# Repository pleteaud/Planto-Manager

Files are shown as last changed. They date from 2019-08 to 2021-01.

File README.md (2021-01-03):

# Planto-Manager

## Description: 
This is an embedded project aimed at monitoring and caring for a potted plant. Device is able to monitor room temperature and humidity using the [DHT11](https://www.adafruit.com/product/386). It can also measure the soil moisture by utilizing a personally designed soil moisture sensor, influenced by [Grove's Capacitor Soil Moisture Sensor](https://wiki.seeedstudio.com/Grove-Capacitive_Moisture_Sensor-Corrosion-Resistant/). Additionally, the device is able to track time and set alarms using the [DS3231](https://components101.com/modules/ds3231-rtc-module-pinout-circuit-datasheet) RTC module. A [16x2 Character LCD](https://www.sparkfun.com/products/709)  was used to display relevant information. Lastly, given the simplicity of the tasks and the low cost, the firmware was developed on an Atmega328P.

## Libraries:
  [Atmel Start Configuration Files](https://start.atmel.com/#dashboard)

## Images:

### Planto Manager System 
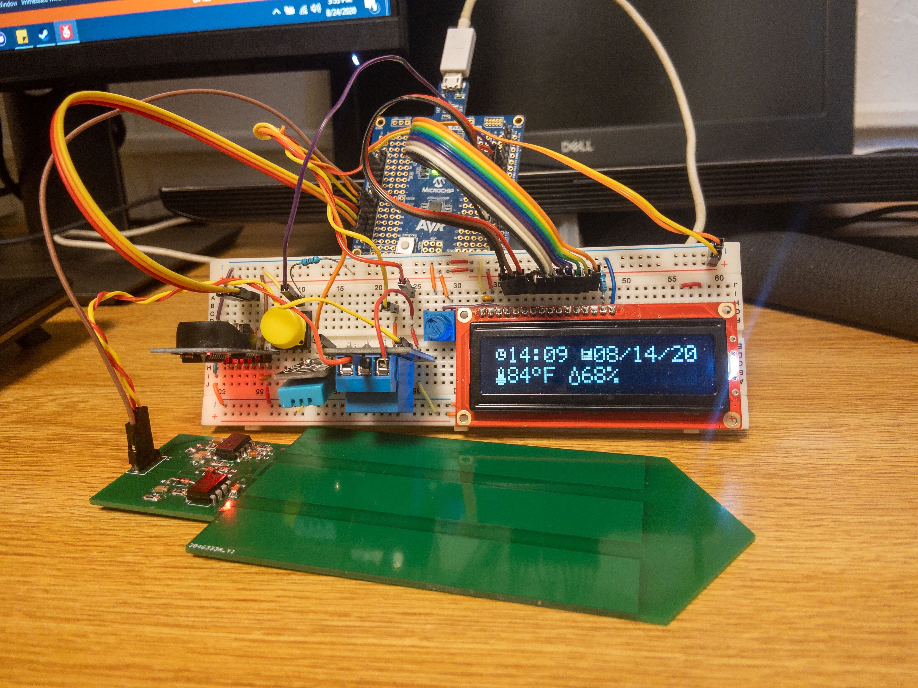
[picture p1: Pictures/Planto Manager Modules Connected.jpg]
Planto Manager System


### Planto Manager System Wiring
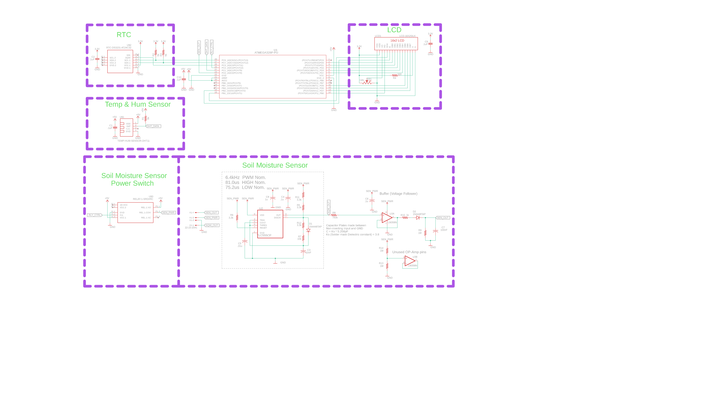
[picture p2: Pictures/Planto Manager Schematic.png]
Planto Manager System Wiring


### Soil Moisture Sensor PCB Layout
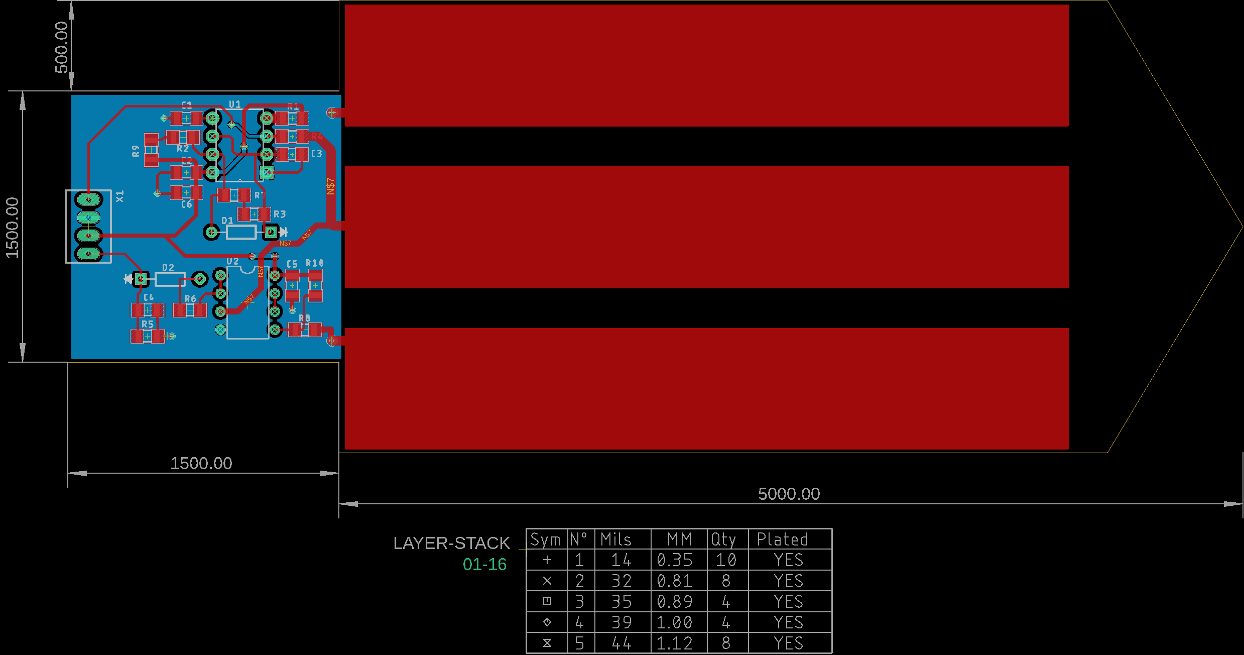
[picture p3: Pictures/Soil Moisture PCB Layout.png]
Soil Moisture Sensor PCB Layout


### Soil Moisture Sensor Reading (Dry Case)
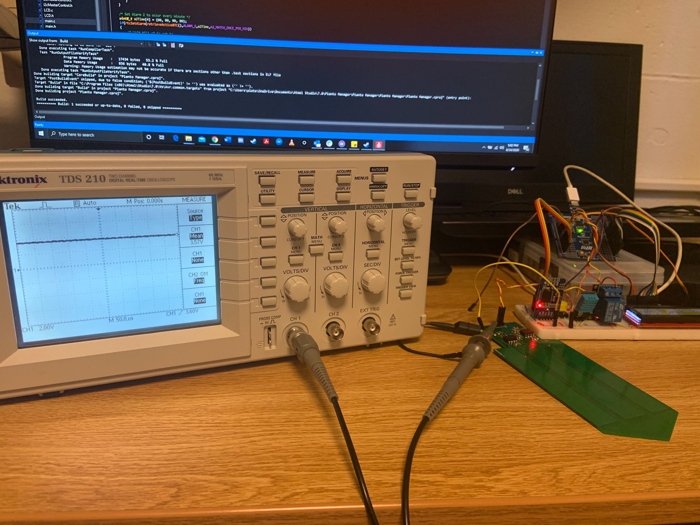
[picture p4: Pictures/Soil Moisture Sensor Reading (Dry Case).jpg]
Soil Moisture Sensor Reading (Dry Case)


### Soil Moisture Sensor Reading (Moist Case)
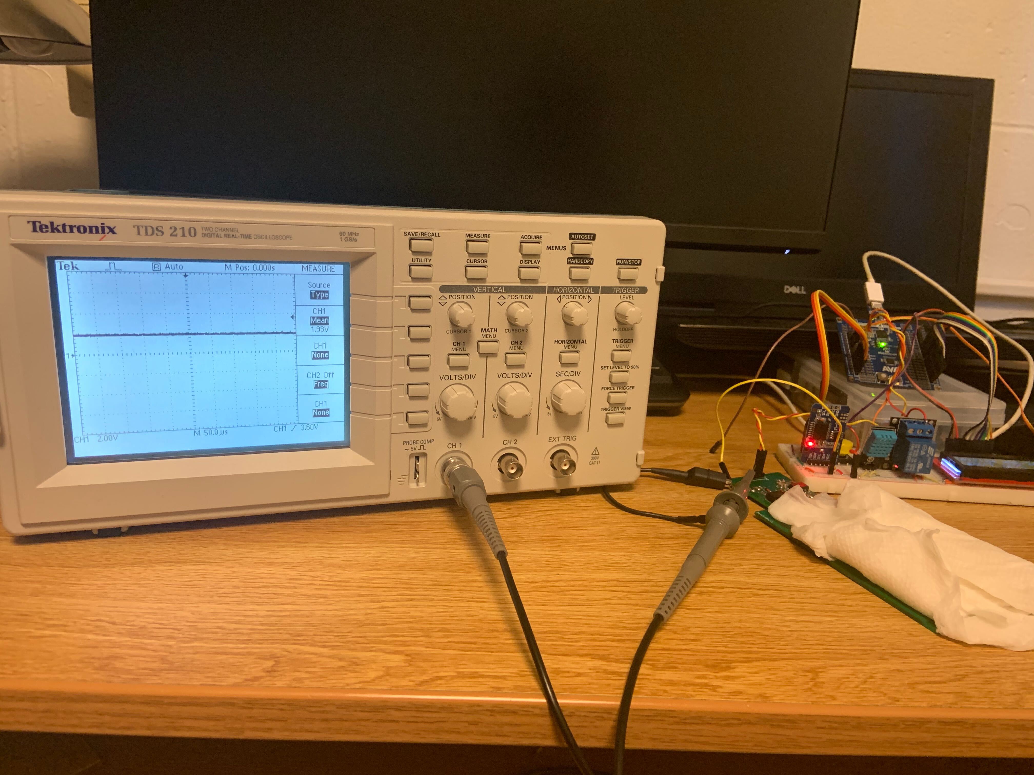
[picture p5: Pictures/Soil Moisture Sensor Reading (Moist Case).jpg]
Soil Moisture Sensor Reading (Moist Case)


## Future Plan
- [ ] Switch to Adafruit BME280 sensor since it supports I2C. This will free up pins and reduce the timing issues faced with the DHT11
- [ ] Implement a Keypad module to allow user to inter inferace with device out of debug mode.
- [ ] Fix Soil moisture sensor code bugs.
- [ ] Implement I2C I/O Expander (MCP23017-E/SP-ND) to reduce number of pins used by the LCD and Keypad
- [ ] Implement reworks and design upgrades to Soil Moisture Sensor
- [ ] Design and build container for device

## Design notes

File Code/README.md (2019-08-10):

# Plant-Manager
Embedded project to manage and track a garden's progress

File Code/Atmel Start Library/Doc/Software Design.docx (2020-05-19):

Software Design:

- What should our microcontroller be able to do
  - Turn on the water pump to water the plants
    - Is it possible to vary how much water is being pumped by varying how fast the pump is moving?
    - Use a Normally-Open Single Pole Single Throw relay to turn on and off the water pump.
  - Calculate how moist or dy the soil is
    - Maybe calculate how long it takes for the soil to typically dry up within a week?
    - Use two probs to measure the resistance between the soil.
  - Gather data about temperature, humidity
    - If temperature is super-hot it could be worth implementing a failsafe to turn on the water to water them. But maybe we should check the moisture first.
    - Connect temp/humidity sensor to adc channels of microcontroller
  - Notify user if there’s no water
    - Send user an email/text/ some for of notification when water reservoir is empty
  - Plant Stats
    - Keep track of height of plants
    - Determine if plant has produced veggies
    - Determine if those veggies are good /have fallen?
    - Store these data somewhere

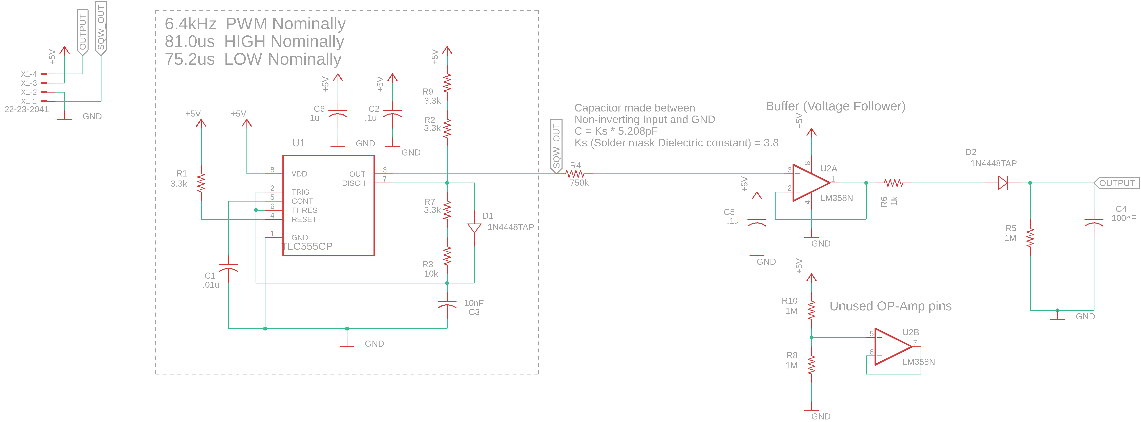
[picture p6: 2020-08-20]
Pictures/Soil Moisture Schematic.png

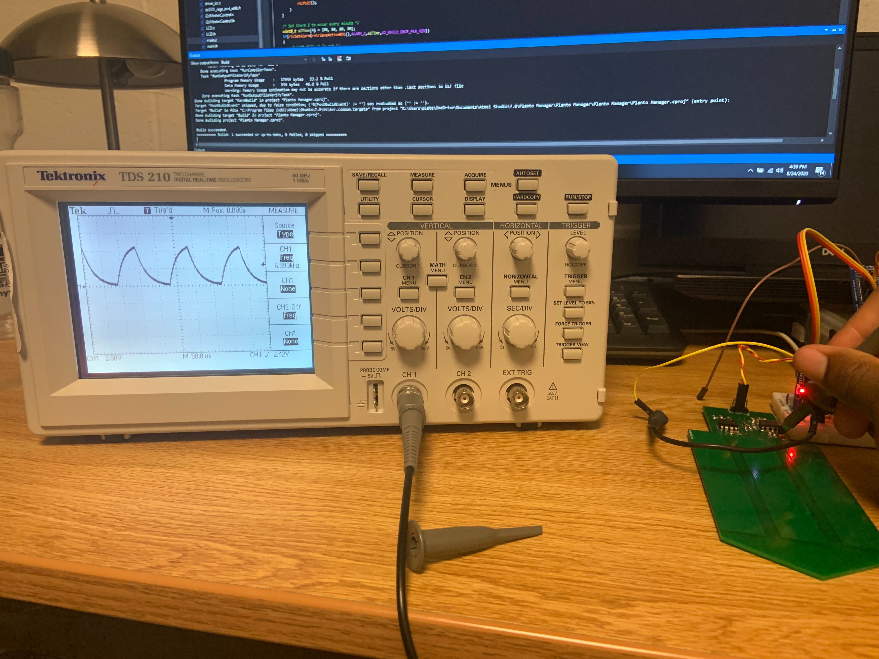
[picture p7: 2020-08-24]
Pictures/Passive Intergrator Signal.jpg

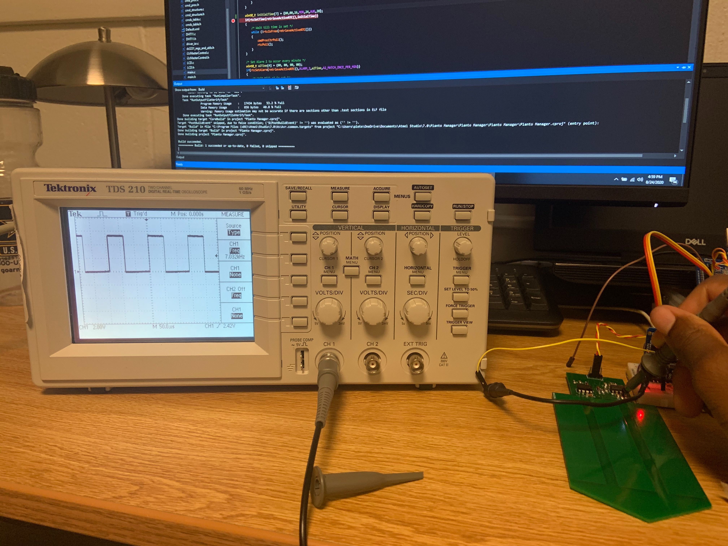
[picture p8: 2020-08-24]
Pictures/Output of Timer 555.jpg

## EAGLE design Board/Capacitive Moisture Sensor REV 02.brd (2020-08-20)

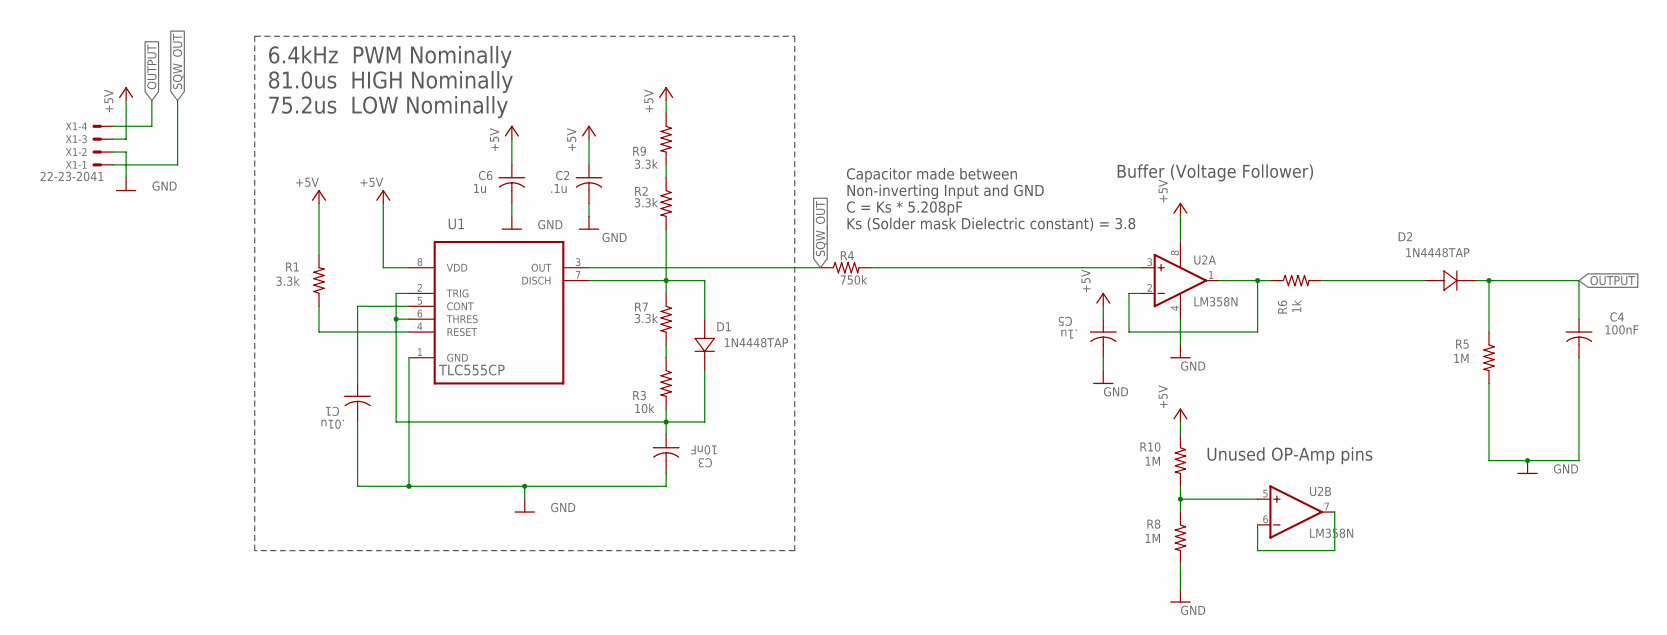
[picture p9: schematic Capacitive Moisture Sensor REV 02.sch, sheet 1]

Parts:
C1: .01u; C1206
C2, C5: .1u; C1206
C3: 10nF; C1206
C4: 100nF; C1206
C6: 1u; C1206
D1, D2: 1N4448TAP; DO-35
R1, R2, R7, R9: 3.3k; R1206
R3: 10k; R1206
R4: 750k; R1206
R5, R8, R10: 1M; R1206
R6: 1k; R1206
U1: TLC555CP; DIP254P762X508-8
U2: LM358N; DIL08
X1: 22-23-2041

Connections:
+5V: C2.1, C5.1, C6.1, R1.2, R9.1, R10.1, U1.8 (VDD), U2.8 (V+), X1.3
GND: C1.2, C2.2, C3.2, C4.2, C5.2, C6.2, R5.2, R8.2, U1.1 (GND), U2.4 (V-), X1.2
unnamed: U2.6 (-IN), U2.7 (OUT)
unnamed: C3.1, D1.1, R3.2, U1.2 (TRIG), U1.6 (THRES)
unnamed: R1.1, U1.4 (RESET)
unnamed: C1.1, U1.5 (CONT)
unnamed: D2.2, R6.2
unnamed: R3.1, R7.2
unnamed: R4.2, U2.3 (+IN)
unnamed: R2.1, R9.2
unnamed: R6.1, U2.1 (OUT), U2.2 (-IN)
unnamed: D1.2, R2.2, R7.1, U1.7 (DISCH)
unnamed: R8.1, R10.2, U2.5 (+IN)
OUTPUT: C4.1, D2.1, R5.1, X1.4
SQW_OUT: R4.1, U1.3 (OUT), X1.1

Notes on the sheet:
Buffer (Voltage Follower)
6.4kHz PWM Nominally 81.0us HIGH Nominally 75.2us LOW Nominally
Capacitor made between Non-inverting Input and GND C = Ks * 5.208pF Ks (Solder mask Dielectric constant) = 3.8
Unused OP-Amp pins

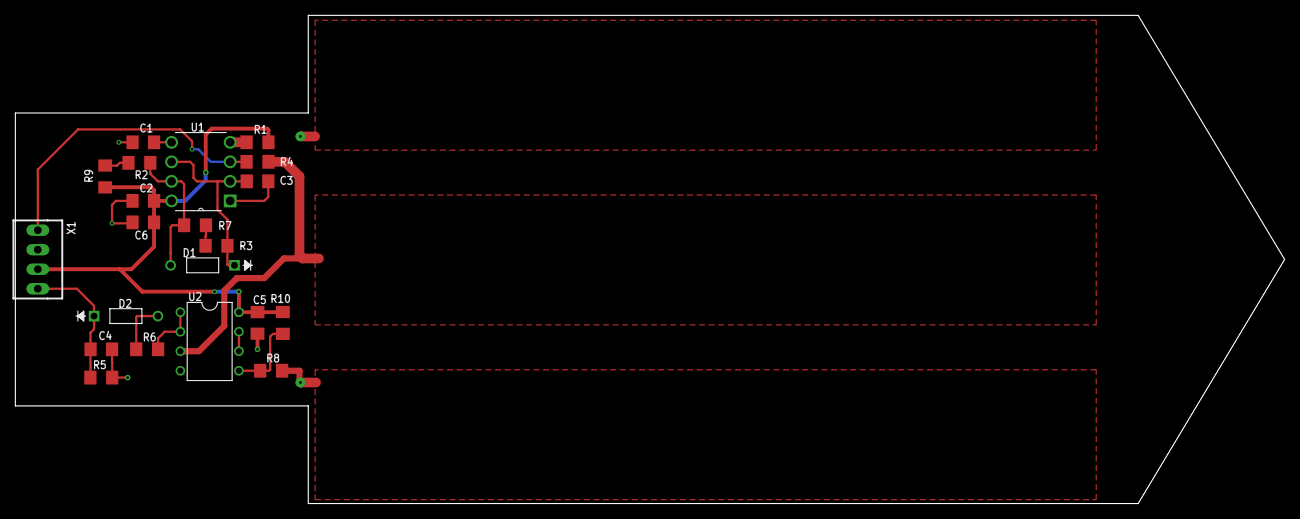
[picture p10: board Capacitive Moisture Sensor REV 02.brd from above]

Board: 2 copper layers, 165.1 x 63.5 mm, 22 parts (0 on the bottom side), 15 nets.

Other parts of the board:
DRILEGEND: DRILEGEND

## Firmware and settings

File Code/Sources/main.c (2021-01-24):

#include "main.h"

/* Instantiate LCD, RTC, and BME sensor */
lcd_t lcd;
ds3231_t ds3231;
struct bme280_dev dev;
mcp23017_t ioExpander;
keypad_t keypad;

/* Custom Pattern byte for clock */
unsigned char clockSymbol[] = {0x0,0xe,0x15,0x17,0x11,0xe,0x0,0x00};
uint8_t clkSymLoc = 0;
unsigned char calendarSymbol[] = {0x00,0x11,0x1F,0x13,0x1F,0x1F,0x00,0x00};
uint8_t calSymLoc = 1;

/* Custom pattern bytes for BME sensor */
unsigned char thermoSym[] = {0x04,0x0A,0x0A,0x0E,0x0E,0x1F,0x1F,0x0E};
uint8_t thermSymLoc = 2;
unsigned char degreeSym[] = {0x0C,0x12,0x12,0x0C,0x00,0x00,0x00,0x00};
uint8_t degreeSymLoc = 3;
unsigned char humiditySym[] = {0x04,0x04,0x0A,0x0A,0x11,0x11,0x11,0x0E};
uint8_t humiditySymLoc = 4;

void setTime(ds3231_t *ds3231P, lcd_t *lcdP, keypad_t *keypad);
static uint32_t readDigit(keypad_t *keypadP, char *str);
static void printErrorMessage(lcd_t *lcdP, char *msg);

static bool updateFlag = false;
int main(void)
{
 	/* Initializes MCU, drivers and middleware */
 	atmel_start_init();
	 
 	// Start free running timer 
 	startMillisTimer();
 	/* Initialize keypad */
 	keypadInit(&keypad);

 	/* Initialize I2C */
  	i2cMasterInit(0);

  	/* Initialize mcp23017 */
  	mcp23017Init(&ioExpander, 0, &DDRB, &PORTB, PINB3); // Pin B 3 is reset pin

 	
 	/* Initialize LCD */
 	lcdInit(&lcd, &ioExpander, &DDRB, &PORTB, PINB0, PINB1, PINB2, true, false);

// 	/* Initialize bme sensor */
// 	uint8_t devAddr = BME280_I2C_ADDR_PRIM;
// 	initBME(&dev, userI2cRead, userI2cWrite, userDelayUs, &devAddr);
// 	
 	/* Initialize and Configure RTC */
 	ds3231Init(&ds3231);
	 
 	// Set Alarm 2 to occur every minute
 	uint8_t a2Time[4] = {00, 00, 00, 00};	 
	ds3231SetAlarm2(&ds3231, a2Time, A2_MATCH_ONCE_PER_MIN, setUpdateFlag, NULL);
 	
	// Set time 
 	printTime(&lcd, &ds3231);
 	printSymbols(&lcd);
 	setTime(&ds3231, &lcd, &keypad);

	/* Build and print special symbols */

 	char s;
 	while(1)
 	{
 		s = getKeyPress(&keypad);
 		ds3231Poll(&ds3231);
 		if(updateFlag)
 		{
 			printTime(&lcd, &ds3231);
 			//if(!getSensorDataForcedMode(&lcd, &dev))
//
 			//{
//
 				////print error
//
 			//}

 			updateFlag = false;

 		}
 	}
	
}

/* Alarm 2 callback function to indicate ds3231 has been updated */
void setUpdateFlag()
{
	updateFlag = true;
}

/* Print time on LCD */
void printTime(lcd_t *lcdP, ds3231_t *ds3231P)
{
	// Set cursor to (0,1) to print Hour:Min in LCD
	lcdSetCursor(lcdP, 0, 1);
	char lcdBuff[20] = {0};
	
	// Print Hour and Minute
	snprintf(lcdBuff, 20, "%02x:%02x", ds3231.time[TIME_UNITS_HR], ds3231.time[TIME_UNITS_MIN]);
	lcdPrint(lcdP, lcdBuff);
	
	// Set cursor to (0,7) to print Date/month/year on LCD 
	lcdSetCursor(lcdP, 0, 8);
	
	// Print date
	snprintf(lcdBuff, 20,"%02x/%02x/%02x", ds3231.time[TIME_UNITS_MO_CEN] & 0x1F, ds3231.time[TIME_UNITS_DT],
										ds3231.time[TIME_UNITS_YR]);
	lcdPrint(lcdP, lcdBuff);
	lcdHome(lcdP);
}

/* Print and Build symbols. Will only be called once */
void printSymbols(lcd_t *lcdP)
{
	/* Build and print themometer and degree symbol */
	lcdBuildSym(lcdP, thermSymLoc,thermoSym);
	lcdBuildSym(lcdP, degreeSymLoc,degreeSym);
	lcdSetCursor(lcdP, 1,0);
	lcdPrintSymbol(lcdP, thermSymLoc);
	lcdSetCursor(lcdP, 1,6);
	lcdPrintSymbol(lcdP, degreeSymLoc);
	lcdPrint(lcdP, "F");
	
	/* Build and print humidity symbol*/
	lcdBuildSym(lcdP, humiditySymLoc,humiditySym);
	lcdSetCursor(lcdP, 1,9);
	lcdPrintSymbol(lcdP, humiditySymLoc);
	lcdSetCursor(lcdP, 1,15);
	lcdPrint(lcdP, "%");
	
	/* Build and Print clock symbol */
	lcdBuildSym(lcdP, clkSymLoc, clockSymbol); 
	lcdSetCursor(lcdP, 0,0);
	lcdPrintSymbol(lcdP, clkSymLoc);
	
	/* Build and print calendar symbol */
	lcdBuildSym(lcdP, calSymLoc,calendarSymbol);
	lcdSetCursor(lcdP, 0,7);
	lcdPrintSymbol(lcdP, calSymLoc);
	
	/* Print moisture Symbol */	
	
	lcdHome(lcdP);
}

/* Print BME280 temperature, humidity, and pressure */
void printBMEdata(lcd_t *lcdP, struct bme280_data *comp_data)
{
	
	float temp, press, hum;
		temp = 0.01f * comp_data->temperature;
		press = 0.0001f * comp_data->pressure;
		hum = 1.0f / 1024.0f * comp_data->humidity;
	
	#ifdef BME280_FLOAT_ENABLE
		temp = comp_data->temperature;
		press = 0.01 * comp_data->pressure;
		hum= comp_data->humidity;
	#else
	#ifdef BME280_64BIT_ENABLE
		temp = 0.01f * comp_data->temperature;
		press = 0.0001f * comp_data->pressure;
		hum = 1.0f / 1024.0f * comp_data->humidity;
	#else
		temp = 0.01f * comp_data->temperature;
		press = 0.01f * comp_data->pressure;
		hum = 1.0f / 1024.0f * comp_data->humidity;
	#endif
	#endif
	
	/* Print temperature */
	char lcdBuff[20] = {0}; // lcd buffer
	
	temp = (temp * 1.8) + 32; //convert to F
	
	/* Get interger and fractional value to print on lcd (floats don't work)*/
	unsigned int intergralVal = temp; 
	unsigned int fractionalVal = (temp - (uint32_t)temp) * 100;
	
	snprintf(lcdBuff, 20, "%u.%02u", intergralVal, fractionalVal);
	lcdSetCursor(lcdP, 1, 1);
	lcdPrint(lcdP, lcdBuff); // print
	
	/* Print humidity */
	intergralVal = hum;
	fractionalVal = (hum - (uint32_t)hum) * 100;
	
	snprintf(lcdBuff, 20, "%u.%02u", intergralVal, 3);
	lcdSetCursor(lcdP, 1, 10);
	lcdPrint(lcdP, lcdBuff); // Print
}

/* Initialize a BME sensor */
uint8_t initBME(struct bme280_dev *sensor, int8_t (*userI2cRead)(uint8_t reg_addr, uint8_t *reg_data, uint32_t len, void *intf_ptr),
				int8_t (*userI2cWrite)(uint8_t reg_addr, uint8_t *reg_data, uint32_t len, void *intf_ptr),
				void (*userDelayUs)(uint32_t period, void *intf_ptr),
				uint8_t *i2cAddr)
			
{
	int8_t rslt = BME280_OK;

	dev.intf_ptr = i2cAddr;
	dev.intf = BME280_I2C_INTF;
	dev.read = userI2cRead;
	dev.write = userI2cWrite;
	dev.delay_us = userDelayUs;

	rslt = bme280_init(&dev);
	return rslt;
} 

/* BME function to execute an i2c read */
int8_t userI2cRead(uint8_t reg_addr, uint8_t *reg_data, uint32_t len, void *intf_ptr)
{
	 int8_t rslt = 1; /* Return 0 for Success, non-zero for failure */
	 uint8_t *i2cDevAddr = (uint8_t *)intf_ptr;
	 
    /*
     * The parameter intf_ptr can be used as a variable to store the I2C address of the device
     */
	
	// Transmit address
	if (i2cMasterTransmit(*i2cDevAddr, &reg_addr, 1))
		// Read BME sensor
		if (i2cMasterRead(*i2cDevAddr, reg_data, len)) 
			rslt = 0;
	
    return rslt;
}

/* BME function to execute an i2c write */
int8_t userI2cWrite(uint8_t reg_addr, uint8_t *reg_data, uint32_t len, void *intf_ptr)
{
	 int8_t rslt = 1; /* Return 0 for Success, non-zero for failure */
	 uint8_t *i2cDevAddr = (uint8_t *)intf_ptr;
	 
	/* Copy reg_data and store reg_addr in the front. this prevents doing 2 i2c transmissions */
	uint8_t newRegData[len + 1];
	newRegData[0] = reg_addr; 
	
	// Copy reg_data
	for (uint8_t i = 0; i < len; i ++)
		newRegData[i + 1] = *(reg_data + i);
	
	// Transmit data
	if (i2cMasterTransmit(*i2cDevAddr, newRegData, len + 1))
		rslt = 0;
    
	return rslt;
}


/* BME function to execute a microseconds delay */
void userDelayUs (uint32_t period, void *intf_ptr)
{
	micro_delay(period);
}

/* BME Function to execute a sensor read */
int8_t getSensorDataForcedMode(lcd_t *lcdP, struct bme280_dev *dev)
{
    int8_t rslt;
    uint8_t settings_sel;
	uint32_t req_delay;
    struct bme280_data comp_data;

    /* Recommended mode of operation: Indoor navigation */
    dev->settings.osr_h = BME280_OVERSAMPLING_1X;
    dev->settings.osr_p = BME280_OVERSAMPLING_16X;
    dev->settings.osr_t = BME280_OVERSAMPLING_2X;
    dev->settings.filter = BME280_FILTER_COEFF_16;

    settings_sel = BME280_OSR_PRESS_SEL | BME280_OSR_TEMP_SEL | BME280_OSR_HUM_SEL | BME280_FILTER_SEL;

    rslt = bme280_set_sensor_settings(settings_sel, dev);
	
	if (rslt != BME280_OK)
		return rslt;
	
	/*Calculate the minimum delay required between consecutive measurement based upon the sensor enabled
     *  and the oversampling configuration. */
    req_delay = bme280_cal_meas_delay(&dev->settings) * 1000;
	

	/* Get sensor data */
	rslt = bme280_set_sensor_mode(BME280_FORCED_MODE, dev);
		
	if (rslt != BME280_OK)
		return rslt;
	/* Wait for the measurement to complete and print data @25Hz */
	dev->delay_us(req_delay, dev->intf_ptr);
	rslt = bme280_get_sensor_data(BME280_ALL, &comp_data, dev);
		
	if (rslt != BME280_OK)
		return rslt;
		
	dev->delay_us(1000000, dev->intf_ptr);

	
    printBMEdata(lcdP, &comp_data);
		
    return rslt;
}

void setTime(ds3231_t *ds3231P, lcd_t *lcdP, keypad_t *keypad)
{
	uint8_t time[7] = {0};
	bool status = false;
	
	char message[] = "Invalid Time";
	lcdSetCursor(lcdP, 0, 1);
	
	uint8_t i = TIME_UNITS_HR;
	while(i != TIME_UNITS_TOTAL)
	{
		// Extract two digits and print to lcd
		for (uint8_t j = 0; j < 2; j++)
		{
			
			char string[2] = {'\0'};
			uint32_t digit = readDigit(keypad, string);
			
			if(string[0] < '0' || string[0] > '9')
			{
				printErrorMessage(lcdP, message);
				return;
			}	
			
			time[i] += (j == 1 ? digit : 10 * digit);
			
			lcdPrint(lcdP, string); //print digit
			milli_delay(150);
		}
		
		switch (i)
		{
			case TIME_UNITS_MIN:
				i = TIME_UNITS_MO_CEN;
				lcdSetCursor(lcdP, 0, 8);
				break;
			case TIME_UNITS_HR:
				i = TIME_UNITS_MIN;
				lcdSetCursor(lcdP, 0, 4);
				break;
			case TIME_UNITS_DY:
				//skip for now. future updates will include that
				break;
			case TIME_UNITS_DT:
				i = TIME_UNITS_YR;
				lcdSetCursor(lcdP, 0, 14);
				break;
			case TIME_UNITS_MO_CEN:
				i = TIME_UNITS_DT;
				lcdSetCursor(lcdP, 0, 11);
				break;
			case TIME_UNITS_YR:
				i = TIME_UNITS_TOTAL;
				break;
		}
	}
	
	if (!ds3231SetTime(&ds3231, time))
		printErrorMessage(lcdP, message);
}

static uint32_t readDigit(keypad_t *keypadP, char *str)
{
	unsigned int digit = 0;
	char s = '\0';
	while(s == '\0')
		s = getKeyPress(keypadP);
		
	sscanf(&s, "%1u", &digit);
	
	// Save the digit inside str if not null
	if(str != NULL)
		*str = s;
			
	return digit;
}

static void printErrorMessage(lcd_t *lcdP, char *msg)
{
	for (uint8_t i = 0; i < 16; i++)
	{
		lcdScrollDisplayLeft(lcdP);
	}
	lcdSetCursor(lcdP, 0, 16);
	lcdPrint(lcdP, msg);
	lcdHome(lcdP);
}

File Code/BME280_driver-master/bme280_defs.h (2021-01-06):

/**
* Copyright (c) 2020 Bosch Sensortec GmbH. All rights reserved.
*
* BSD-3-Clause
*
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
* 1. Redistributions of source code must retain the above copyright
*    notice, this list of conditions and the following disclaimer.
*
* 2. Redistributions in binary form must reproduce the above copyright
*    notice, this list of conditions and the following disclaimer in the
*    documentation and/or other materials provided with the distribution.
*
* 3. Neither the name of the copyright holder nor the names of its
*    contributors may be used to endorse or promote products derived from
*    this software without specific prior written permission.
*
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
* @file       bme280_defs.h
* @date       2020-03-28
* @version    v3.5.0
*
*/

#ifndef BME280_DEFS_H_
#define BME280_DEFS_H_

/********************************************************/
/* header includes */
#ifdef __KERNEL__
#include <linux/types.h>
#include <linux/kernel.h>
#else
#include <stdint.h>
#include <stddef.h>
#endif

/********************************************************/
/*! @name       Common macros               */
/********************************************************/

#if !defined(UINT8_C) && !defined(INT8_C)
#define INT8_C(x)    S8_C(x)
#define UINT8_C(x)   U8_C(x)
#endif

#if !defined(UINT16_C) && !defined(INT16_C)
#define INT16_C(x)   S16_C(x)
#define UINT16_C(x)  U16_C(x)
#endif

#if !defined(INT32_C) && !defined(UINT32_C)
#define INT32_C(x)   S32_C(x)
#define UINT32_C(x)  U32_C(x)
#endif

#if !defined(INT64_C) && !defined(UINT64_C)
#define INT64_C(x)   S64_C(x)
#define UINT64_C(x)  U64_C(x)
#endif

/**@}*/
/**\name C standard macros */
#ifndef NULL
#ifdef __cplusplus
#define NULL         0
#else
#define NULL         ((void *) 0)
#endif
#endif

/********************************************************/

#ifndef BME280_64BIT_ENABLE /*< Check if 64-bit integer (using BME280_64BIT_ENABLE) is enabled */
#ifndef BME280_32BIT_ENABLE /*< Check if 32-bit integer (using BME280_32BIT_ENABLE) is enabled */
#ifndef BME280_FLOAT_ENABLE /*< If any of the integer data types not enabled then enable BME280_FLOAT_ENABLE */
#define BME280_64BIT_ENABLE
#endif
#endif
#endif

#ifndef TRUE
#define TRUE                                      UINT8_C(1)
#endif
#ifndef FALSE
#define FALSE                                     UINT8_C(0)
#endif

/**
 * BME280_INTF_RET_TYPE is the read/write interface return type which can be overwritten by the build system.
 */
#ifndef BME280_INTF_RET_TYPE
#define BME280_INTF_RET_TYPE                      int8_t
#endif

/**
 * The last error code from read/write interface is stored in the device structure as intf_rslt.
 */
#ifndef BME280_INTF_RET_SUCCESS
#define BME280_INTF_RET_SUCCESS                   INT8_C(0)
#endif

/**\name I2C addresses */
#define BME280_I2C_ADDR_PRIM                      UINT8_C(0x76)
#define BME280_I2C_ADDR_SEC                       UINT8_C(0x77)

/**\name BME280 chip identifier */
#define BME280_CHIP_ID                            UINT8_C(0x60)

/**\name Register Address */
#define BME280_CHIP_ID_ADDR                       UINT8_C(0xD0)
#define BME280_RESET_ADDR                         UINT8_C(0xE0)
#define BME280_TEMP_PRESS_CALIB_DATA_ADDR         UINT8_C(0x88)
#define BME280_HUMIDITY_CALIB_DATA_ADDR           UINT8_C(0xE1)
#define BME280_PWR_CTRL_ADDR                      UINT8_C(0xF4)
#define BME280_CTRL_HUM_ADDR                      UINT8_C(0xF2)
#define BME280_CTRL_MEAS_ADDR                     UINT8_C(0xF4)
#define BME280_CONFIG_ADDR                        UINT8_C(0xF5)
#define BME280_DATA_ADDR                          UINT8_C(0xF7)

/**\name API success code */
#define BME280_OK                                 INT8_C(0)

/**\name API error codes */
#define BME280_E_NULL_PTR                         INT8_C(-1)
#define BME280_E_DEV_NOT_FOUND                    INT8_C(-2)
#define BME280_E_INVALID_LEN                      INT8_C(-3)
#define BME280_E_COMM_FAIL                        INT8_C(-4)
#define BME280_E_SLEEP_MODE_FAIL                  INT8_C(-5)
#define BME280_E_NVM_COPY_FAILED                  INT8_C(-6)

/**\name API warning codes */
#define BME280_W_INVALID_OSR_MACRO                INT8_C(1)

/**\name Macros related to size */
#define BME280_TEMP_PRESS_CALIB_DATA_LEN          UINT8_C(26)
#define BME280_HUMIDITY_CALIB_DATA_LEN            UINT8_C(7)
#define BME280_P_T_H_DATA_LEN                     UINT8_C(8)

/**\name Sensor power modes */
#define BME280_SLEEP_MODE                         UINT8_C(0x00)
#define BME280_FORCED_MODE                        UINT8_C(0x01)
#define BME280_NORMAL_MODE                        UINT8_C(0x03)

/**\name Macro to combine two 8 bit data's to form a 16 bit data */
#define BME280_CONCAT_BYTES(msb, lsb)             (((uint16_t)msb << 8) | (uint16_t)lsb)
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

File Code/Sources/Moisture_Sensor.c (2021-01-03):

/*
 * Moisture_Sensor.c
 *
 * Created: 5/17/2020 6:07:41 PM
 *  Author: Davo Pleteau
 */

/************************************************************************/
/*                     Includes/Constants/Globals                       */
/************************************************************************/ 
#include "Moisture_Sensor.h"
#include "adc_basic.h"
#include "LCD.h"
#include "stdio.h"
#include "timer.h"



/* Setup relay port */
#define RELAY_DDR					DDRC
#define RELAY_PORT					PORTC
#define RELAY_OUTOUT_PIN			PINC2

/* Setup Calibration Button */
#define CAL_BTN_DDR			DDRB
//#define CAL_BTN_PORT		PORTB
#define CAL_BTN_INPUT_PIN	PINB
#define CAL_BTN_PIN_NUM		PINB3


#define SENS_ADC_CHAN_NUM			(0x00)

static bool sampleFlag = false;
static bool alarmTrigFlag = false;

/* Upper and lower bound for soil moisture value */
static volatile double soilWetVal = 0; // lower bound
static volatile double soilDryVal = 0; // upper bound
static volatile double oldRange = 0; // Moisture Range

/* Water Content Symbol */
unsigned char soilSenSymb[] = {0x0E,0x11,0x11,0x1F,0x11,0x11,0x0E,0x00};
uint8_t soilSenSymLoc = 5;
/************************************************************************/
/*                      Private Function Declaration                    */
/************************************************************************/

static adc_irq_cb_t adcReadCompCB();
static void printSoilMoist(uint8_t moisture);
static void waitForBtnPress();


/************************************************************************/
/*                      Public Functions Implementations                */
/************************************************************************/

/* Turn on Relay to power moisture sensor */
void soilSenPwrRelay(bool relayState)
{
	if(relayState)
	{
		/* Turn On relay to power sensors */
		RELAY_PORT |= (1<< RELAY_OUTOUT_PIN);
	}
	else
	{
		/* Turn off sensor */
		RELAY_PORT &= ~(1<< RELAY_OUTOUT_PIN);
	}	
}

/* Initialize moisture sensor object's data members */
void soilSensInit(soil_moisture_sensor_t *sensorP)
{
	//sensorP->state = MS_UNCALIBRATED;
	//sensorP->sampleNum = sensorP->timeStamp = 0;
	//sensorP->calibrateFlag = false;
	///* Configure pin DDRx as output low for relay control */
	//RELAY_DDR |= (1 << RELAY_OUTOUT_PIN);
	//soilSenPwrRelay(false);
	///* Register callback for ADC sensor reading completion */
	//ADC_0_register_callback(adcReadCompCB);
	//
	///* Configure Calibration Button */
	//CAL_BTN_DDR &= ~(1 << CAL_BTN_PIN_NUM); // Intput pin 
	///* Build and print water content symbol*/
	//lcdBuildSym(soilSenSymLoc,soilSenSymb);
	//lcdSetDDRAMAdrr(1,11);
	//lcdWriteSymbol(soilSenSymLoc);
	//lcdWriteString("00%");
}

/* Retrieve sensor's soil moisure reading */
double soilSenGetMoisture(soil_moisture_sensor_t *sensorP)
{
	return sensorP->moisture;
}

/* Calibrate the upper and lower bound for soil moisture */
void soilSenCalibrate(soil_moisture_sensor_t *sensorP)
{
	///* Determine the value of the moisture, when soil is dry (upper bound) */ 
	//sensorP->calibrateFlag = true;
	//sensorP->state = MS_IDLE;
	//soilSenPwrRelay(true);
	//alarmTrigFlag = true;
	//
	///* Indicate to user now calibrating the value of the sensor when soil is dry */
	//lcdSetDDRAMAdrr(0,16);
	//lcdWriteString("Calibrating S-M:");
	//lcdSetDDRAMAdrr(1,16);
	//lcdWriteString("Maximum Dryness");
	//milli_delay(250);
	///* Wait for user to press the calibration button to begin measurement */
	//waitForBtnPress();
	//lcdSetDDRAMAdrr(0,16);
	//lcdWriteString("  Release Button  ");
	//lcdSetDDRAMAdrr(1,16);
	//lcdWriteString("To Begin Reading");
	///* Give user a second to release button */
	//milli_delay(1000);
	//
	///* Read sensor value */
	//readSens(sensorP);
	///* Store ADC value when soil is dry */
	//soilDryVal = soilSenGetMoisture(sensorP);
	//
	//
	///* Determine the value of the moisture. when soil is wet (lower bound) */
	//soilSenPwrRelay(true);
	//alarmTrigFlag = true;
	//
	///* Indicate to user now calibrating the value of the sensor when soil is wet */
	//lcdSetDDRAMAdrr(0,16);
	//lcdWriteString("Calibrating S-M:");
	//lcdSetDDRAMAdrr(1,16);
	//lcdWriteString("Maximum Wetness ");
	//milli_delay(250);
	///* Wait for user to press the calibration button to begin measurement */
	//waitForBtnPress();
	//lcdSetDDRAMAdrr(0,16);
	//lcdWriteString("  Release Button  ");
	//lcdSetDDRAMAdrr(1,16);
	//lcdWriteString("To Begin Reading");
	///* Give user a second to release button */
	//milli_delay(1000);
	//
	///* Read sensor value */
	//readSens(sensorP);
	///* Store ADC value when soil is wet */
	//soilWetVal = soilSenGetMoisture(sensorP);
	//
	///* Update range for linear transformation */
	//oldRange = soilDryVal-soilWetVal;
	//if (oldRange == 0)
	//{
		///* Indicate to user there was an error calibrating sensor and set state to "Uncalibrated" to prevent invalid math operations (e.g 0/0) */
		//lcdSetDDRAMAdrr(0,16);
		//lcdWriteString("Calibrating S-M:");
		//lcdSetDDRAMAdrr(1,16);
		//lcdWriteString("Error: Bad Range");
		//sensorP->state = MS_UNCALIBRATED;
	//}
	//else
	//{
		///* Indicate successful calibration*/
		//lcdSetDDRAMAdrr(0,16);
		//lcdWriteString("Calibrating S-M:");
		//lcdSetDDRAMAdrr(1,16);
		//lcdWriteString("    Complete    ");
	//}
	//sensorP->calibrateFlag = false;
	//soilSenPwrRelay(false);
	//return;
}

void readSens(soil_moisture_sensor_t *sensorP)
{
	soilSenPwrRelay(true);
	milli_delay(10);
	/* Start to read */
	for (int i = 0; i < 10; i++)
	{
		/* Initiate an ADC Conversion */
		ADC_0_start_conversion(SENS_ADC_CHAN_NUM);
		sensorP->moisture += ADC_0_get_conversion(SENS_ADC_CHAN_NUM);
	}
	/* Turn off Sensor */
	soilSenPwrRelay(false);
	/* Take the average of the readings */

	sensorP->moisture /= 5;
	
	/* If we are calibrating, don't print and leave moisture value as an average */
	if(sensorP->calibrateFlag){return;}
	
	/* Convert average moisture calculated to a value between 0-100 */
	/* If value is closer to 0, soil is moist. If value is closer to 100, soil is dry */
	double newMin = 0, newMax = 100;
	double newRange = newMax - newMin; /* 0-100 */
	sensorP->moisture = ((sensorP->moisture-soilWetVal)/oldRange)*(newRange) + newMin;
	
	/* Print Moisture on LCD */
	printSoilMoist((uint8_t)sensorP->moisture);

}

/************************************************************************/
/*                     Private Functions Implementation                 */
/************************************************************************/


/* Callback function to indicate a sampling of the ADC has been complete */
static adc_irq_cb_t adcReadCompCB()
{
	sampleFlag = true;
}

static void printSoilMoist(uint8_t moisture)
{
	char buff[20];
	/* Print moisture */
	lcdSetDDRAMAdrr(1,12);
	if (moisture < 10){lcdWriteString("0");}
	snprintf(buff,20,"%d", moisture);
	lcdWriteString(buff);
	lcdWriteString("%");	
}
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

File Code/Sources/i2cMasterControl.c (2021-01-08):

/*
 * i2cMasterControl.c
 *
 * Created: 7/16/2019 9:57:40 PM
 *  Author: plete
 */ 

/************************************************************************/
/*							Includes/Constants	 	                    */
/************************************************************************/
#include "i2cMasterControl.h"
#include <driver_init.h>
#include <stdbool.h>

#define MAX_ERRORS		(0x100)

/************************************************************************/
/*							Enums Definition		 	                */
/************************************************************************/
enum
{
	writeCollision = 1,
	addressNACK,
	dataNACK,
	timeOut,
	reset
};
/************************************************************************/
/*                      Private Variables                               */
/************************************************************************/
static uint8_t errorList[MAX_ERRORS];
static uint8_t errorListCount;
static bool busy;
static bool error;

/************************************************************************/
/*                      Private Function Declaration                    */
/************************************************************************/
static i2c_operations_t i2cMasterReturnStopCb(void *p);
static i2c_operations_t i2cMasterReturnResetCb(void *p);
static i2c_operations_t i2cMasterRestartWriteCb(void *p);
static i2c_operations_t i2cMasterRestartReadCb(void *p);
static i2c_operations_t i2cWriteCollisionErrCB(void *p);
static i2c_operations_t i2cAdrrNackCB(void *p);
static i2c_operations_t i2cTimeoutErrCB(void *p);
static i2c_operations_t i2cDataNackCB(void *p);

/************************************************************************/
/*                      Public Functions Implementations                */
/************************************************************************/
/* Initialize I2C; Set up address; Assign callback functions */
void i2cMasterInit(const uint8_t slaveAddress)
{
	I2C_0_open(slaveAddress);
	I2C_0_set_data_complete_callback(i2cMasterReturnStopCb,NULL);
	I2C_0_set_write_collision_callback(i2cWriteCollisionErrCB,NULL);	
	I2C_0_set_address_nack_callback(i2cAdrrNackCB, NULL);
	I2C_0_set_data_nack_callback(i2cDataNackCB, NULL);
	I2C_0_set_timeout_callback(i2cTimeoutErrCB,NULL);	
	busy = false;
}

void i2cMasterChangeAddr(const uint8_t newAddr)
{
	I2C_0_set_address(newAddr);
}

bool i2cMasterTransmit(const uint8_t newAddr, uint8_t *payload, const uint8_t dataSize)
{
	// Change I2C address
	i2cMasterChangeAddr(newAddr);
	
	busy = true;
	
	/* Reset CR Register before start new I2C transmission */
	resetI2c();
	
	/* Set buffer */
	I2C_0_set_buffer(payload, dataSize);
	
	/* Start I2C write */
	if(I2C_0_master_operation(false) != I2C_BUSY)
		while (busy){} // wait till we're done reading
	return !error;
}

bool i2cMasterRead(const uint8_t newAddr, uint8_t *buffP, const uint8_t size)
{
	// Change I2C address
	i2cMasterChangeAddr(newAddr);
	
	busy = true;
	
	/* Reset CR Register before start new I2C transmission */
	resetI2c();
	
	/* Set buffer */
	I2C_0_set_buffer(buffP, size);
	
	/* Start I2C read */
	if(I2C_0_master_operation(true) != I2C_BUSY)
		while (busy){} // wait till we're done reading
	return !error;
}

/* Reset I2C Control Registers for next communication */
void resetI2c()
{
	// Reset bus by sending STOP
	TWCR = ((1 << TWSTO) | (1 << TWINT));
	// Reset module
	TWCR = (1 << TWINT) | (1 << TWEN);
	// uncomment the IRQ enable for an interrupt driven driver.
	TWCR |= (1 << TWIE);
	error = false;
}

bool returnBusy()
{
	return busy;
}

/************************************************************************/
/*                     Private Functions Implementation                 */
/************************************************************************/
/* Callback function to handle the returning stop state of I2C.*/
static i2c_operations_t i2cMasterReturnStopCb(void *p)
{
	busy = false;
	return i2c_stop;
}

static i2c_operations_t i2cMasterReturnResetCb(void *p)
{
	return i2c_reset_link;
}

static i2c_operations_t i2cMasterRestartWriteCb(void *p)
{
	return i2c_restart_write;
}

static i2c_operations_t i2cMasterRestartReadCb(void *p)
{
	return i2c_restart_read;
}
static i2c_operations_t i2cWriteCollisionErrCB(void *p)
{
	errorList[errorListCount++] = writeCollision;
	busy = false;
	error = true;
	return i2c_stop;
}
static i2c_operations_t i2cAdrrNackCB(void *p)
{
	errorList[errorListCount++] = addressNACK;
	busy = false;
	error = true;
	return i2c_stop;
}
static i2c_operations_t i2cTimeoutErrCB(void *p)
{
	errorList[errorListCount++] = timeOut;
	busy = false;
	error = true;
	return i2c_reset_link;
}

static i2c_operations_t i2cDataNackCB(void *p)
{
	errorList[errorListCount++] = dataNACK;
	busy = false;
	error = true;
	return i2c_stop;
}

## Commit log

2019-08-16 initial version of interrupt routine
2019-08-16 Created initial version of i2c manager object. Currently, there's only helper functions, but in a week I'll add the struct
2019-08-18 added a function to set rtc device's control register.Lenght of commands are now calculated using sizeof __cmdType__
2020-05-19 Project Document
    [TLC555astable_b(AutoRecovered).xls]
2020-05-19 Board Layout and Schematic
    [Capacitive Moisture Sensor.brd, Capacitive Moisture Sensor.sch]
2020-05-19 Temperature and Moisture sensor code added
2020-05-19 Removing duplicates
    [Capacitive Moisture Sensor.brd, Capacitive Moisture Sensor.sch, TLC555astable_b(AutoRecovered).xls]
2020-05-19 Revert "Temperature and Moisture sensor code added"
    This reverts commit 3d2d300fd749efcdf5ff3812b05353742edbb3e9.
    [Moisture_Sensor.c, adc_basic.c]
2020-05-19 xRevert "Revert "Temperature and Moisture sensor code added""
    This reverts commit 201d351d41fd05fb5b25cc0a1de2bad0640da718.
    [Moisture_Sensor.c, adc_basic.c]
2020-05-19 reupload of deleted files
    [Capacitive Moisture Sensor.brd, Capacitive Moisture Sensor.sch, TLC555astable_b(AutoRecovered).xls]
2020-05-20 Tweaked method to initiate temp/hum reading. Added function to turn on or off relay. Tweaked buggs
    [Moisture_Sensor.c, main.c]
2020-05-29 Made modification and reworks after testing and debugging board
    [Capacitive Moisture Sensor REV 2.brd, Capacitive Moisture Sensor REV 2.sch]
2020-05-29 Completed board layout for rework modification
    [Capacitive Moisture Sensor REV 02.brd, Capacitive Moisture Sensor REV 02.sch]
2020-05-29 removed duplicates
    [Capacitive Moisture Sensor REV 2.brd, Capacitive Moisture Sensor REV 2.sch]
2020-07-08 Create DHT11-Technical-Data-Sheet-Translated-Version-1143054.pdf
    Added DHT11 Sensor Datasheet
2020-07-11 Added Sensor Calibration Function
    -Added sensor calibration function
    -Designed output moisture value to be between 0-100
2020-08-08 Update DS3231.pdf
    Datasheet for DS3231 RTC Timer
2020-08-08 Created I2C control Code.
    Will update with I2C object if I feel the Atmega code doesn't suffice
    [i2cMasterControl.c]
2020-08-08 Updated RTC code
    -Moved all command intiation and preparation function to withing RTC object's control. (Alarm object can no longer initiate the command to set Alarm registers).
    -Added a state machine and polling function for RTC
    -Reduce number of commands to 6: set alarm 1 and 2, set control register, set status register, set time, read all registers.
    -Future updates will add more command
    [rtc.c]
2020-08-08 Update driver_isr.c
    Added an interrupt vector for external interrupts
2020-08-14 Update driver_isr.c
    Removed External Pin interrupt.
2020-08-14 Update i2cMasterControl.c
    Added header to file to get rid of indirect reference to functions in cmd_proc
2020-08-14 Updated RTC interface firmware
    -Added enum for months
    -Altered process of updating time and handling alarm interrupts. Instead of using external interrupts, we are simply going to poll the INT pin state. I've made this change because, most of the times 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
    -Added LCD interface code to print out time
2020-08-14 Update driver_init.c
    Removed External interrupts. No longer needed
    [driver_init.c]
2020-08-14 Update i2c_master.c
    Accidently modified this function. it should be reset
    [i2c_master.c]
2020-08-14 Updated Timer Control
    Update Timer values to reflect the change I made to the CPU frequency (now 16MHz)
2020-08-15 Update DHT11.c
    Moved location where data is printed on LCD screen
2020-08-15 Update rtc.c
    Fixed location where data is printed on the LCD screen
    [rtc.c]
2020-08-15 Integrated Soil Moisture
    -Unfortunately my Xplained board broke. I need to get a new one to completely test and debug the intergration.
    [Moisture_Sensor.c, main.c]
2020-08-20 Create TLC555astable.xls
    Updated version of Astable 555 timer calculator sheet
    [TLC555astable.xls]
2020-08-20 Updated text in schematic
    [Capacitive Moisture Sensor REV 02.brd, Capacitive Moisture Sensor REV 02.sch]
2020-08-20 Board Schematic and Layout pictures
2020-08-20 Create Soil Moisture Brought Up Board.jpg
2020-08-21 Added description to schematic
    [Capacitive Moisture Sensor REV 02.sch]
2020-08-21 Created a wiring schematic of all the modules in the project
    [Planto Manager Wiring.sch]
2020-08-21 Create Planto Manager Schematic.png
2020-08-24 Create Planto Manager Modules Connected.jpg
    Picture of all the modules of the project connected. Did not print the reading from soil moisture sensor since it's been buggy.
2020-08-24 changed relay and dht11 pins
    [Planto Manager Wiring.sch]
2020-08-24 Create Output of Timer 555.jpg
2020-08-24 Create Soil Moisture Sensor Reading (Dry Case).jpg
2020-08-24 Create Soil Moisture Sensor Reading (Moist Case).jpg
2020-08-24 Changed TCNT value to get timer to be more accurate
2020-08-24 Updated Moisture Sensor Methods and Structure
    -House Keeping
    -Changed pin for relay control
    - Switching to blocking method for reading sensor as opposed to non-blocking (polling/interrupts) since currently our code is breaking using that method.
    - There is a frustrating bug with the software written for the soil moisture. For some unknown reason the I can debug correctly when using it. Furthermore the readings are inaccurate. I suspect my math may be wrong.
    [Moisture_Sensor.c]
2020-08-24 Added some LCD prints to indicate object initializations
    -removed calls to sensor object. It seems to be breaking the code.
2021-01-03 Added the BME280 Driver Library
2021-01-03 No used for this object. Switched to BME280 sensor
2021-01-03 Deleted because the correct file is "i2cMasterControl"
2021-01-03 Designed LCD object. Added public interfaces
    Switched to LCD-1602CA
2021-01-06 Made an error flag the output of trasmit and read functions.
    [i2cMasterControl.c]
2021-01-06 Iplemented the printing methods for time, temperature, and humidity
    Added support for the BME sensor
2021-01-07 Initilized the mcp object in main and passed to the lcd object to communicate via i2c
2021-01-07 Fixed the inccorect initialization of array
    [rtc.c]
2021-01-08 Changed signatures of functions / housekeeping
    -Added const modifer where appropriate
    -Changes size of error list
    [i2cMasterControl.c]
2021-01-24 Added function to allow user to set time && print error encounted
    [main.c]

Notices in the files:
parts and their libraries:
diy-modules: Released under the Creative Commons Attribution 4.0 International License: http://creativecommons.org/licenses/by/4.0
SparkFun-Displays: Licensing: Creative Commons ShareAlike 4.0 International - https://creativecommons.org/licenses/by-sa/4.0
